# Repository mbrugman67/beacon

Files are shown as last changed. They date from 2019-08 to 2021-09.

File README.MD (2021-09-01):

# Beacon
This is a funky looking visual status indicator I made for work:  
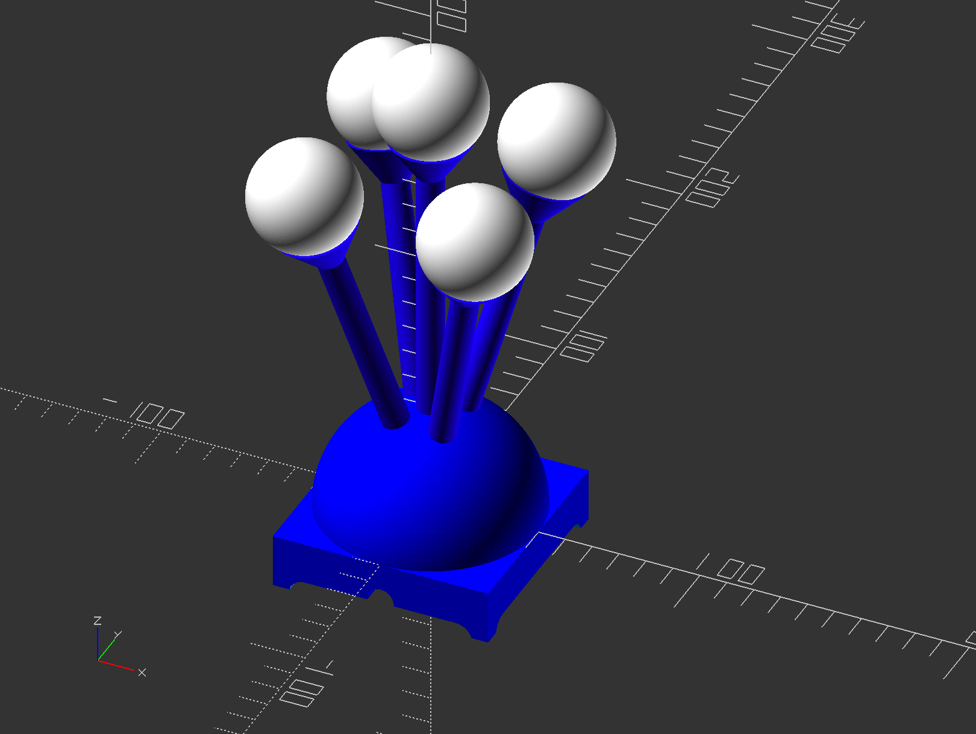
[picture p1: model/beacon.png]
Here
  
It has a hemispherical base with 5 stalks ending in cups into which I glued ping-pong balls.  In each ping pong ball is an 8mm addressable through-hole LED.  Wires run down the stalks to a small ATMega32u4 dev board.  

The idea is that you plug it into your computer's USB port and set it at the top of a cube wall.  It lets others around you know if you're there, away, busy, etc.  

The original version was used on a Linux computer, and I added code to Pidgin to change the LED states based on my Skype for Business status.  Now, my work computer is Windows (ugh), and I have to get admin approval to get access to the API for MS Teams - so now I have a separate Windows program where I manually change the LED states.  Progress (nope).

The components:
## avr
This is the AVR code in the dev board.  I don't use Arduino, so this is c++ code compiled and flashed into the chip.  It is a pretty basic project that I've pulled some external stuff into.  In the directories:
+ (root) - has main, a common header, and some basic classes.  `btBootycall` is a OSX application that is used to call the AVR into bootloader 
  +  `sys` - code to set up the hardware and the fuses
  +  `usb` - copied and modified from Atmel's application notes on writing a USB HID device
  +  `ws2812` - a library for ws2812 protocol LEDs

There's a Makefile for linux and mac.  A Windows makefile is left as an exercise for the reader.

## model
This is the OpenSCAD model for the physical device.  Pretty self-explanatory.  

## osx
This is an open-source HID library that I used to make a test app to talk to the beacon for development

## proMicro
Documentation on the dev board

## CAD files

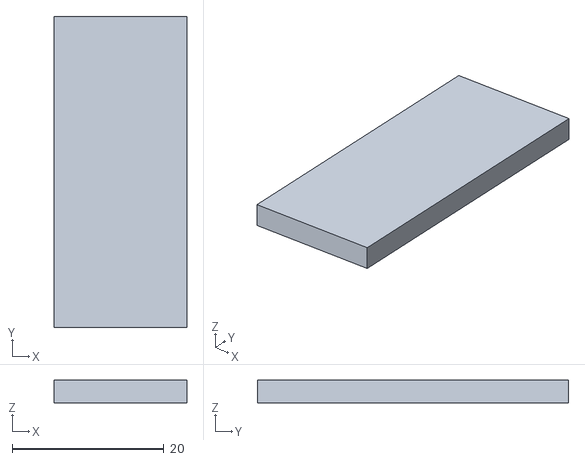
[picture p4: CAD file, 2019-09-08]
model/stl/boardSupport.stl
17.5 x 41.0 x 3.00

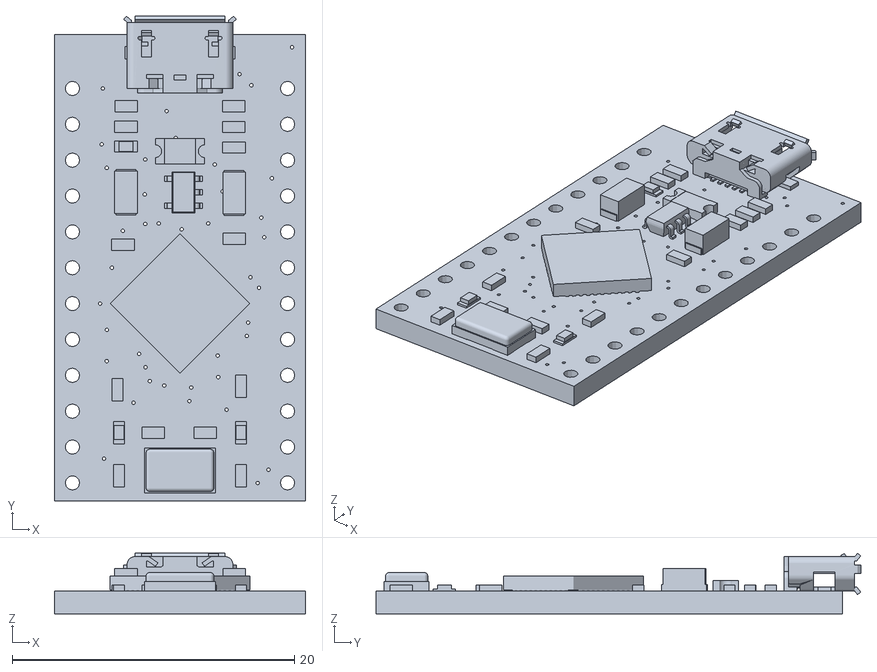
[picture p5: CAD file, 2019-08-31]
proMicro/stl/Pro_Micro.stl
17.8 x 34.3 x 4.30

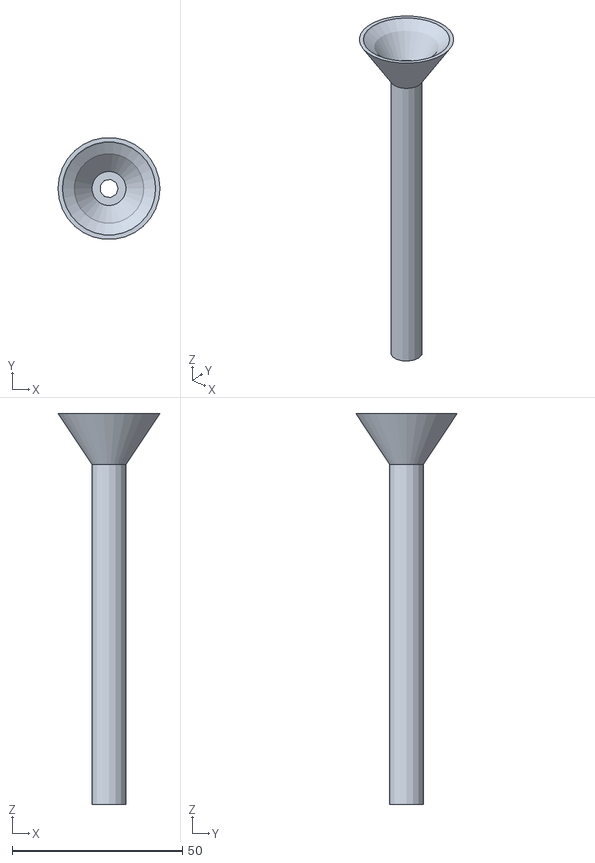
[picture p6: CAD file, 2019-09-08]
model/stl/largeBeacon.stl
30.0 x 29.8 x 115.0

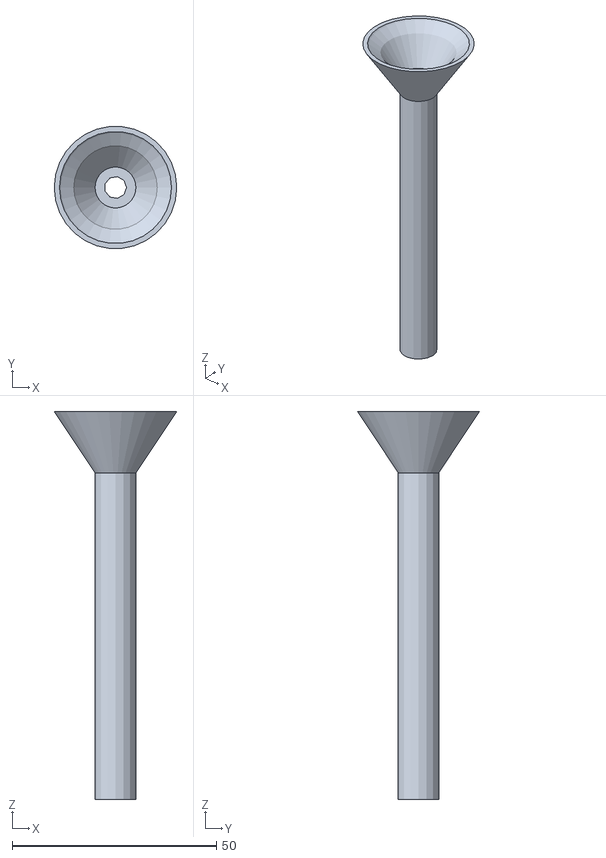
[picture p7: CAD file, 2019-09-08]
model/stl/smallBeacon.stl
30.0 x 29.8 x 95.0

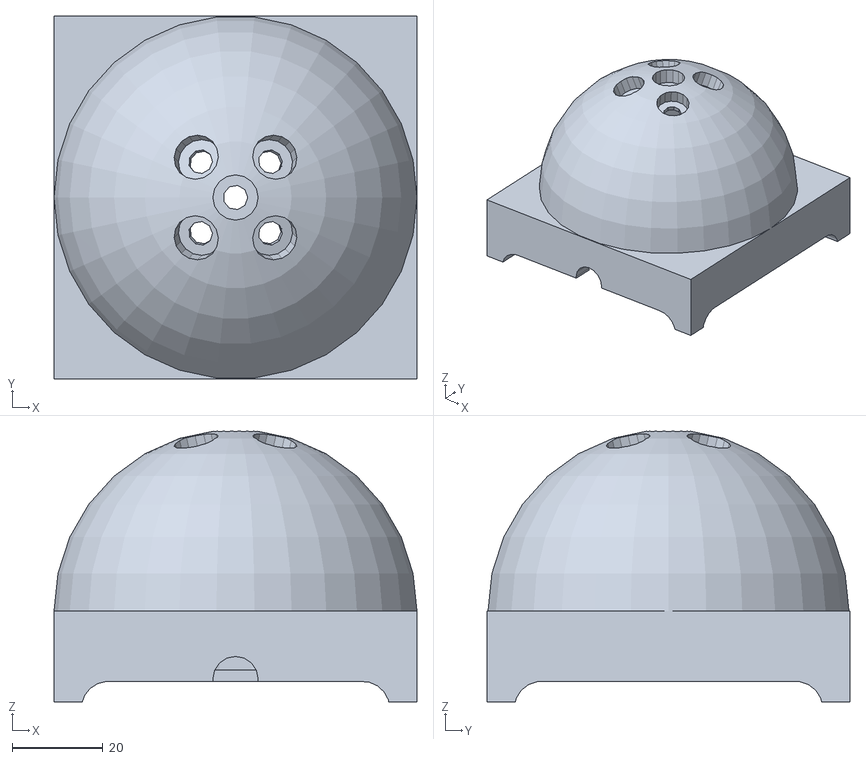
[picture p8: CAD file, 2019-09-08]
model/stl/base.stl
80.0 x 80.0 x 59.6

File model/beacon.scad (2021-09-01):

//-----------------------------
// beacon
//-----------------------------
DRAW_BEACONS = true;
LARGE_BEACON_ONLY = false;
SMALL_BEACON_ONLY = false;
DRAW_BASE = true;
DRAW_BOARD_SUPPORT = false;

SHAFT_RADIUS = 5;
SHAFT_TUNNEL_RADIUS = 2.7;
BALL_RADIUS = 20;
CONE_HEIGHT = 15;
CONE_MAJOR_RADIUS = 15;
OFFSET_ANGLE = 13;
WALL_THICKNESS = 6;
BASE_HEIGHT = 20;

module beacon(x, y, z, h, draw_sphere = true)
{
   BALL_TO_CONE_DEPTH = 4.5;
   
   difference()
   {
      color([.1, 0, 1])
      {
         translate([x, y, z + h / 2])
         cylinder(h, SHAFT_RADIUS, SHAFT_RADIUS, true, $fn=100);

         translate([x, y, z + h + (CONE_HEIGHT / 2)])
         cylinder(CONE_HEIGHT, SHAFT_RADIUS, CONE_MAJOR_RADIUS, true, $fn=100);
      }
   
      color([0, 1, 0])
      {
         translate([0, 0, z + (h + 12) / 2])
         cylinder(h + 24, SHAFT_TUNNEL_RADIUS, SHAFT_TUNNEL_RADIUS, true, $fn=100);
         
         translate([x, y, h + z + (CONE_HEIGHT / 2) + BALL_TO_CONE_DEPTH])
         cylinder(CONE_HEIGHT, SHAFT_RADIUS, CONE_MAJOR_RADIUS, true, $fn=100);
         
         translate([0, 0, z + h + SHAFT_RADIUS + BALL_RADIUS + BALL_TO_CONE_DEPTH], $fn=100)
         sphere(BALL_RADIUS);
      }
   }
   
   if (draw_sphere == true)
   {
      color([1, 1, 1])
      translate([0, 0, z + h + SHAFT_RADIUS + BALL_RADIUS + BALL_TO_CONE_DEPTH])
      sphere(BALL_RADIUS, $fn=360);
   }
}

module base(x, y, z, r)
{
   difference()
   {
      color([0, 0, 1])
      translate([x, y, z])
      sphere(r, $fn=100);
      
      sphere(r - WALL_THICKNESS);
      
      translate([x, y, -r / 2])
      cube([r * 2 + 1, r * 2 + 1, r], true);
      
      translate([0, 0, r - SHAFT_RADIUS / 2])
      {
         cylinder(WALL_THICKNESS * 2, SHAFT_TUNNEL_RADIUS, SHAFT_TUNNEL_RADIUS, true, $fn=100);
         cylinder(WALL_THICKNESS * .8, SHAFT_RADIUS, SHAFT_RADIUS, true, $fn=100);
      }
      
      for (rx = [OFFSET_ANGLE, -OFFSET_ANGLE])
      {
         for (ry = [OFFSET_ANGLE, -OFFSET_ANGLE])
         {
            rotate([rx, ry, 0])
            translate([0, 0, r - SHAFT_RADIUS / 2])
            {
               cylinder(WALL_THICKNESS * 2, SHAFT_TUNNEL_RADIUS, SHAFT_TUNNEL_RADIUS, true, $fn=100);
               cylinder(WALL_THICKNESS * .8, SHAFT_RADIUS, SHAFT_RADIUS, true, $fn=100);
            }
         }
      }      
     
   }
   
   difference()
   {
      color([0, 0, 1])
      translate([x, y, z - BASE_HEIGHT / 2])
      cube([r * 2, r * 2, BASE_HEIGHT], true);
      
      translate([0, 0, z - BASE_HEIGHT / 2 - 1])
      cylinder(BASE_HEIGHT + 4, r - WALL_THICKNESS, r - WALL_THICKNESS, true);

      foot_offset = r - WALL_THICKNESS - 6;
      foot_radius = 6;
      
      for (x1 = [foot_offset, -foot_offset])
      {
         translate([x1, 0, z - BASE_HEIGHT - foot_radius / 4])
         rotate([90, 0, 0])
         cylinder(r * 2 + 2, foot_radius, foot_radius, true);
      }
      
      for (y1 = [foot_offset, -foot_offset])
      {
         translate([0, y1, z - BASE_HEIGHT - foot_radius / 4])
         rotate([0, 90, 0])
         cylinder(r * 2 + 2, foot_radius, foot_radius, true);
      
      }

      translate([0, 0, z - BASE_HEIGHT + foot_radius / 4])
      {
         cube ([foot_offset * 2, r * 2 + 4, foot_radius], true);
         cube ([r * 2 + 4, foot_offset * 2, foot_radius], true);
      }
      
      color([1, 0, 0])
      translate([0, 23, -BASE_HEIGHT + 4 + 1.5])
      cube([17.5, 32, 3], true);
      

      color([0, 0, 1])
      translate([0, -33, -BASE_HEIGHT + 5])
      rotate([90, 90, 0])
      cylinder(20, 5, 5, true);
   }
}

if (DRAW_BASE == true)
{
   base(0, 0, 0, 40);
}

if (DRAW_BEACONS == true)
{
   if (LARGE_BEACON_ONLY == true)
   {
      rotate([0, 0, 0])
      beacon(0, 0, 35, 100, false);
   }
   else if (SMALL_BEACON_ONLY == true)
   {
      rotate([0, 0, 0])
      beacon(0, 0, 35, 80, false);
   }
   else if (DRAW_BOARD_SUPPORT == false)
   {
      rotate([0, 0, 0])
      beacon(0, 0, 35, 100, true);

      for (rx = [OFFSET_ANGLE, -OFFSET_ANGLE])
      {
         for (ry = [OFFSET_ANGLE, -OFFSET_ANGLE])
         {
            rotate([rx, ry, 0])
            beacon(0, 0, 35, 80, true);
         }
      }
   }

   if (DRAW_BOARD_SUPPORT == true)
   {
      // board support
      color([1, 0, 0])
      translate([0, 18, -BASE_HEIGHT + 4 + 1.5])
      cube([17.5, 41, 3], true);
   }
}

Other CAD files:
proMicro/geometry_edit_blender/Pro_Micro.blend
proMicro/skp/Pro_Micro.skp

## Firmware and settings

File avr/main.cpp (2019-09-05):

/**************************************************************
* Beacon RGB (addressable) lighting
***************************************************************/
#include "project.h"

static volatile uint16_t isrMilliseconds;
uint16_t volatile milliseconds = 0;
static uint16_t volatile lastMS = 0;

void setBootloaderAndGo();
uint16_t bootLoaderCrazyValue __attribute__ ((section (".noinit")));
void (*jumpToBL) (void) = (void (*)(void))0x3800;

// global
beacon flow;

int main(void)
{
    // if we were previously running and some host sent us the 
    // feature set SETUP command that sez "Go to bootloader",
    // it would have set this crazy non-init'd value and forced
    // a device reset.  So go to bootloader.
    if (bootLoaderCrazyValue == BOOTLOADER_CODE)
    {
        // don't keep doing it!
        bootLoaderCrazyValue = 0;
        jumpToBL();
    }

    setupPins();        // GPIO pins
    setupTimer0();      // 1ms system tick

    sei();

    // comms to the game (host)
    HOST_COMMS hostComms;

    // loop every millisecond
    while (true)
    {
        // handle tx/rx LED
        handleTXRX();
        
        flow.update();

        // request for bootloader?  Set the non-clearable-on-reset value and force a restart 
        if (hostComms.bootLoaderRequested())
        {
            setBootloaderAndGo();
        }
        
        // Loop here during "dead time" of one ms tick
        do
        {
            // handle USB tasks
            hostComms.update();
            
            // prevent shearing
            ATOMIC_BLOCK(ATOMIC_FORCEON)
            {
                milliseconds = isrMilliseconds;
            } 

        } while (milliseconds == lastMS);

        lastMS = milliseconds;
    }
 
    return 0;
}

void setBootloaderAndGo()
{
    // this variable has been placed in an area of RAM that is not touched
    // by the startup library.  Set it to some crazy unlikely-to-be-randomly
    // set on actual powerup.  
    bootLoaderCrazyValue = BOOTLOADER_CODE;
    
    // detach USB
    CLRBIT(USBCON, USBE);
    
    // short delay to allow the detach to finish
    for (uint16_t detachDelay = 0; detachDelay < 50000; ++detachDelay);

    // enable the watchdog timer, set a short timeout
    wdt_enable(WDTO_500MS);

    // had loop until the watchdog timer resets us
    while(true);
}

/*****************************************************
* System tick ISR.  Once each millisecond
*****************************************************/
ISR(TIMER0_COMPA_vect, ISR_BLOCK)
{
    ++isrMilliseconds;
}

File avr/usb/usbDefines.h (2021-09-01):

/***************************************
* Mostly from ATMEL app notes
***************************************/

#ifndef USB_DEFINES_H_
#define USB_DEFINES_H_

#include <avr/pgmspace.h>

#define MFG_ID          0xb337


#define USB_unicode(a)      ((uint16_t)(a))

// 18 bytes
struct usbDeviceDescriptor
{
    uint8_t     bLength;
    uint8_t 	bDescriptorType;
    uint16_t 	bscUSB;
    uint8_t 	bDeviceClass;
    uint8_t 	bDeviceSubClass;
    uint8_t 	bDeviceProtocol; 
    uint8_t 	bMaxPacketSize0;
    uint16_t 	idVendor;
    uint16_t 	idProduct; 
    uint16_t 	bcdDevice; 
    uint8_t 	iManufacturer;
    uint8_t 	iProduct;
    uint8_t 	iSerialNumber;
    uint8_t 	bNumConfigurations;
};

// 9 bytes
struct S_usb_configuration_descriptor
{
    uint8_t      bLength;              
    uint8_t      bDescriptorType;      
    uint16_t     wTotalLength;         
    uint8_t      bNumInterfaces;       
    uint8_t      bConfigurationValue;  
    uint8_t      iConfiguration;       
    uint8_t      bmAttibutes;          
    uint8_t      MaxPower;             
};

// 9 bytes
struct S_usb_interface_descriptor
{
    uint8_t      bLength;               
    uint8_t      bDescriptorType;       
    uint8_t      bInterfaceNumber;      
    uint8_t      bAlternateSetting;     
    uint8_t      bNumEndpoints;         
    uint8_t      bInterfaceClass;       
    uint8_t      bInterfaceSubClass;    
    uint8_t      bInterfaceProtocol;    
    uint8_t      iInterface;            
};

// 9 bytes
struct S_usb_hid_descriptor
{
    uint8_t     bLength;               // Size of this descriptor in bytes
    uint8_t     bDescriptorType;       // HID descriptor type
    uint16_t    bscHID;                // Binary Coded Decimal Spec. release
    uint8_t     bCountryCode;          // Hardware target country
    uint8_t     bNumDescriptors;       // Number of HID class descriptors to follow
    uint8_t     bRDescriptorType;      // Report descriptor type
    uint16_t    wDescriptorLength;     // Total length of Report descriptor
};

#define SIZE_OF_REPORT          0x35

// 35 bytes
struct S_usb_hid_report_descriptor
{
    uint8_t      report[SIZE_OF_REPORT];
};

// 7 bytes
struct S_usb_endpoint_descriptor
{
    uint8_t      bLength;               
    uint8_t      bDescriptorType;       
    uint8_t      bEndpointAddress;      
    uint8_t      bmAttributes;          
    uint16_t     wMaxPacketSize;        
    uint8_t      bInterval;             
};

// 41 bytes
struct usbUserDeviceDescriptor
{
   S_usb_configuration_descriptor cfg;      //  9 bytes
   S_usb_interface_descriptor     ifc;      //  9 bytes
   S_usb_hid_descriptor           hid;      //  9 bytes
   S_usb_endpoint_descriptor      ep1;      //  7 bytes
   S_usb_endpoint_descriptor      ep2;      //  7 bytes
};

struct S_usb_language_id
{
    uint8_t     bLength;
    uint8_t     bDescriptorType;
    uint16_t    wlangid;
};

struct S_usb_manufacturer_string_descriptor
{
    uint8_t     bLength;
    uint8_t     bDescriptorType;
    uint16_t    wstring[16];
};

struct S_usb_product_string_descriptor
{
    uint8_t     bLength;
    uint8_t     bDescriptorType;
    uint16_t    wstring[32];
};

#define NUMBER_OF_CONFIGURATIONS      1         // number of configurations available

#define EVT_USB_POWERED               1         // USB plugged
#define EVT_USB_UNPOWERED             2         // USB un-plugged
#define EVT_USB_DEVICE_FUNCTION       3         // USB in device
#define EVT_USB_HOST_FUNCTION         4         // USB in host
#define EVT_USB_SUSPEND               5         // USB suspend
#define EVT_USB_WAKE_UP               6         // USB wake up
#define EVT_USB_RESUME                7         // USB resume
#define EVT_USB_RESET                 8         // USB reset

#define MAX_EP_NB             7

#define PIPE_CONTROL          0
#define PIPE_0                0
#define PIPE_1                1
#define PIPE_2                2
#define PIPE_3                3
#define PIPE_4                4
#define PIPE_5                5
#define PIPE_6                6
#define PIPE_7                7

// USB EndPoint
#define MSK_EP_DIR            0x7F
#define MSK_UADD              0x7F
#define MSK_EPTYPE            0xC0
#define MSK_EPSIZE            0x70
#define MSK_EPBK              0x0C
#define MSK_DTSEQ             0x0C
#define MSK_NBUSYBK           0x03
#define MSK_CURRBK            0x03
#define MSK_DAT               0xFF  // UEDATX
#define MSK_BYCTH             0x07  // UEBCHX
#define MSK_BYCTL             0xFF  // UEBCLX
#define MSK_EPINT             0x7F  // UEINT
#define MSK_HADDR             0xFF  // UHADDR

// USB Pipe
#define MSK_PNUM              0x07  // UPNUM
#define MSK_PRST              0x7F  // UPRST
#define MSK_PTYPE             0xC0  // UPCFG0X
#define MSK_PTOKEN            0x30
#define MSK_PEPNUM            0x0F
#define MSK_PSIZE             0x70  // UPCFG1X
#define MSK_PBK               0x0C

#define MSK_NBUSYBK           0x03

#define MSK_ERROR             0x1F
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

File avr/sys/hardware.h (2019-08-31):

#ifndef _HARDWARE_C_
#define _HARDWARE_C_

//#define USB_DEBUGGING
#define USE_DBG_PINS

/**************************************
* OUTPUT LED PINS
***************************************
* PRT PIN WHAT
*  C   6  Top red (AL D5)
*  D   7  Top green (AL D6)
*  E   6  Top blue (AL D7)
*  B   4  Bottom red (AL D8)
*  B   5  Bottom green (AL D9)
*  B   6  Bottom blue (AL D10)
*  D   1  Button red (AL D2)
*  D   0  Button green (AL D3)
*  D   4  Button blue (AL D4)
*
*  B   0  RX LED (AL RXLED)
*  D   5  TX LED (AL TXLED)
*
*  F   7  AUX FET 1 (AL A0)
*  F   6  AUX FET 2 (AL A1)
*
*  B   7  Debug pin 0 (AL D11)
*  D   6  Debug pin 1 (AL D12)
****************************************/

#define LED_RX_OFF()            (SETBIT(PORTB, PORTB0))     // Yah, these look opposite of what
#define LED_TX_OFF()            (SETBIT(PORTD, PORTD5))     // you would expect...
#define LED_RX_ON()             (CLRBIT(PORTB, PORTB0))     // the LEDs have are pulled up to
#define LED_TX_ON()             (CLRBIT(PORTD, PORTD5))     // Vcc, so set output off (to sink) to turn LED on
#define LED_RX(x)               {if (x) {CLRBIT(PORTB, PORTB0);} else {SETBIT(PORTB, PORTB0);}}
#define LED_TX(x)               {if (x) {CLRBIT(PORTD, PORTD5);} else {SETBIT(PORTD, PORTD5);}}
#define TGL_LED_RX()            (SETBIT(PINB, PORTB0))
#define TGL_LED_TX()            (SETBIT(PIND, PORTD5))
#define IS_LED_RX_ON            (GETBIT(PORTB, PORTB0))
#define IS_LED_TX_ON            (GETBIT(PORTD, PORTD5))

#ifndef USB_DEBUGGING
    #define TOP_RED_LED_ON()        (SETBIT(PORTC, PORTC6))
    #define TOP_GRN_LED_ON()        (SETBIT(PORTD, PORTD7))
    #define TOP_BLU_LED_ON()        (SETBIT(PORTE, PORTE6))
    #define TOP_RED_LED_OFF()       (CLRBIT(PORTC, PORTC6))
    #define TOP_GRN_LED_OFF()       (CLRBIT(PORTD, PORTD7))
    #define TOP_BLU_LED_OFF()       (CLRBIT(PORTE, PORTE6))
    #define TGL_TOP_RED_LED()       (SETBIT(PINC, PINC6))
    #define TGL_TOP_GRN_LED()       (SETBIT(PIND, PIND7))
    #define TGL_TOP_BLU_LED()       (SETBIT(PINE, PINE6))
    #define IS_TOP_RED_LED_ON       (GETBIT(PORTC, PORTC6))
    #define IS_TOP_GRN_LED_ON       (GETBIT(PORTD, PORTD7))
    #define IS_TOP_BLU_LED_ON       (GETBIT(PORTE, PORTE6))

    #define BOT_RED_LED_ON()        (SETBIT(PORTB, PORTB4))
    #define BOT_GRN_LED_ON()        (SETBIT(PORTB, PORTB5))
    #define BOT_BLU_LED_ON()        (SETBIT(PORTB, PORTB6))
    #define BOT_RED_LED_OFF()       (CLRBIT(PORTB, PORTB4))
    #define BOT_GRN_LED_OFF()       (CLRBIT(PORTB, PORTB5))
    #define BOT_BLU_LED_OFF()       (CLRBIT(PORTB, PORTB6))
    #define TGL_BOT_RED_LED()       (SETBIT(PINB, PINB4))
    #define TGL_BOT_GRN_LED()       (SETBIT(PINB, PINB5))
    #define TGL_BOT_BLU_LED()       (SETBIT(PINB, PINB6))
    #define IS_BOT_RED_LED_ON       (GETBIT(PORTB, PORTB4))
    #define IS_BOT_GRN_LED_ON       (GETBIT(PORTB, PORTB5))
    #define IS_BOT_BLU_LED_ON       (GETBIT(PORTB, PORTB6))

    #define BTN_RED_LED_ON()        (SETBIT(PORTD, PORTD1))
    #define BTN_GRN_LED_ON()        (SETBIT(PORTD, PORTD0))
    #define BTN_BLU_LED_ON()        (SETBIT(PORTD, PORTD4))
    #define BTN_RED_LED_OFF()       (CLRBIT(PORTD, PORTD1))
    #define BTN_GRN_LED_OFF()       (CLRBIT(PORTD, PORTD0))
    #define BTN_BLU_LED_OFF()       (CLRBIT(PORTD, PORTD4))
    #define TGL_BTN_RED_LED()       (SETBIT(PIND, PIND1))
    #define TGL_BTN_GRN_LED()       (SETBIT(PIND, PIND0))
    #define TGL_BTN_BLU_LED()       (SETBIT(PIND, PIND4))
    #define IS_BTN_RED_LED_ON       (GETBIT(PORTD, PORTD1))
    #define IS_BTN_GRN_LED_ON       (GETBIT(PORTD, PORTD0))
    #define IS_BTN_BLU_LED_ON       (GETBIT(PORTD PORTD4))

    #define AUX_FET_0_ON()          (SETBIT(PORTF, PORTF7))
    #define AUX_FET_0_OFF()         (CLRBIT(PORTF, PORTF7))
    #define TGL_AUX_FET_0()         (SETBIT(PINF, PINF7))
    #define IS_AUX_FET_0_ON         (GETBIT(PORTF, PORTF7))
    #define AUX_FET_1_ON()          (SETBIT(PORTF, PORTF6))
    #define AUX_FET_1_OFF()         (CLRBIT(PORTF, PORTF6))
    #define TGL_AUX_FET_1()         (SETBIT(PINF, PINF6))
    #define IS_AUX_FET_1_ON         (GETBIT(PORTF, PORTF6))


    #ifdef USE_DBG_PINS
        #define DEBUG_PIN0(x)           {if (x) {SETBIT(PORTB, PORTB7);} else {CLRBIT(PORTB, PORTB7);}}
        #define DEBUG_PIN1(x)           {if (x) {SETBIT(PORTD, PORTD6);} else {CLRBIT(PORTD, PORTD6);}}
        #define TGL_DEBUG_PIN0()        (SETBIT(PINB, PINB7))
        #define TGL_DEBUG_PIN1()        (SETBIT(PIND, PORTD6)) 
        #define IS_DEBUG_PIN0           (GETBIT(PORTB, PORTB7))
        #define IS_DEBUG_PIN1           (GETBIT(PORTD, PORTD6))
    #endif

    #define DBG_COUNT_ON_0(x)
    #define DBG_COUNT_ON_1(x)
    #define DBG_COUNT_ON_2(x)
    #define DBG_COUNT_ON_3(x)
    #define DBG_COUNT_ON_4(x)
    #define DBG_COUNT_ON_5(x)
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

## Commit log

2019-09-05 moar cleanup
    [beacon.scad]
2019-09-08 model updates
    [base.stl, beacon.scad, boardSupport.stl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]
